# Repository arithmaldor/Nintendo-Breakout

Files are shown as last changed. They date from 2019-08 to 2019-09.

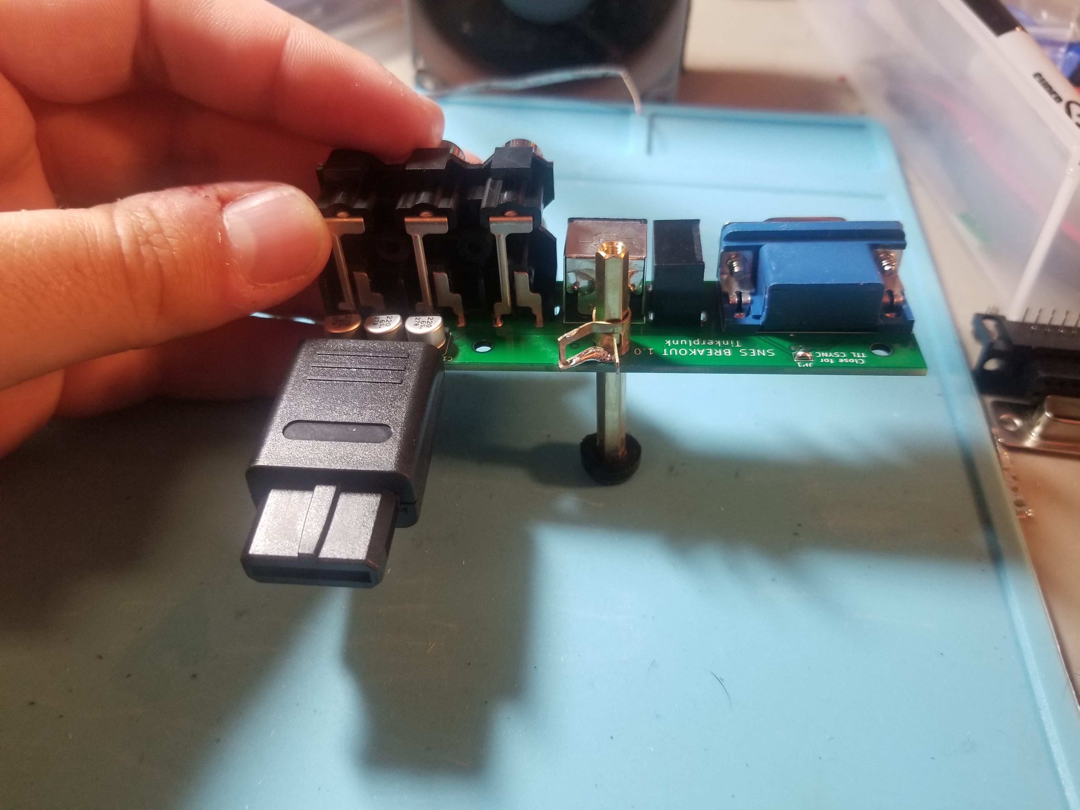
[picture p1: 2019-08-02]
Photos/20190725_023714.jpg

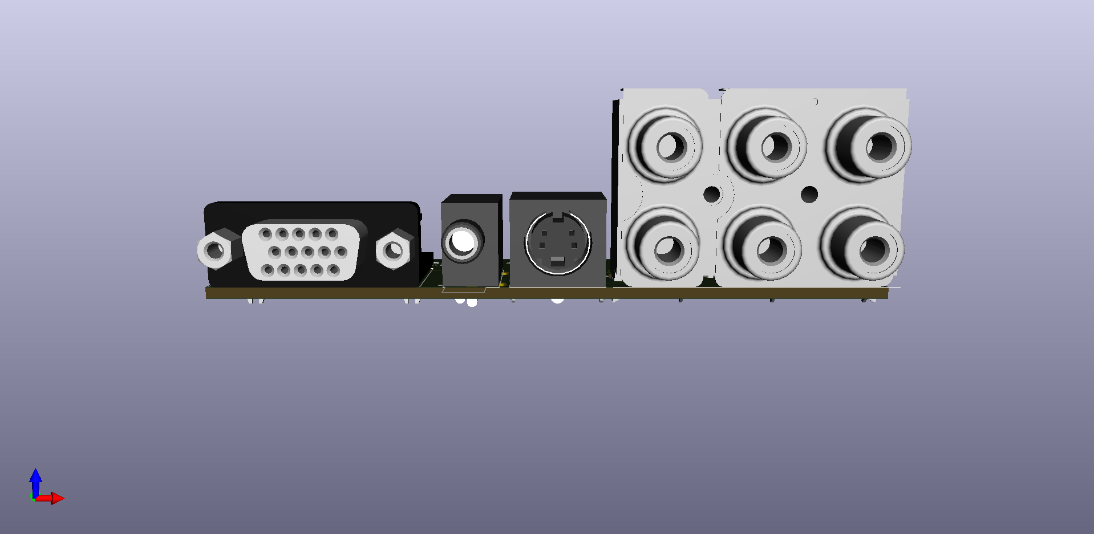
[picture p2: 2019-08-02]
Renders/Front 3D.png

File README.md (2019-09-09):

# Copyright and Disclaimer
Copyright: Jacob Proctor

This documentation describes Open Hardware and is licensed under the
CERN OHL v. 1.2.

You may redistribute and modify this documentation under the terms of the
CERN OHL v.1.2. (http://ohwr.org/cernohl). This documentation is distributed
WITHOUT ANY EXPRESS OR IMPLIED WARRANTY, INCLUDING OF
MERCHANTABILITY, SATISFACTORY QUALITY AND FITNESS FOR A
PARTICULAR PURPOSE. Please see the CERN OHL v.1.2 for applicable
conditions

# Nintendo Multi-out Breakout
Breaks out all of the signals from the Nintendo Muliout so you can easily access them. 

# Operation
Plug in and go. There is a solder jumper to set the csync coming from the HD-15 port as TTL or 75ohm. Closed is TTL, open is 75 ohm. If you only plan to use this in TTL mode the resistor is not required.
This adapter can only break out signals that are already present. Unmodded SNES Jr. will only output composite, unmodded N64's will only ouput CVBS and S-video, same for Gamecube.
A cool extra feature is that this breakout lets you easily output component YPbPr from the GCDual and N64Advanced mods.

# PAL Systems
This was designed with NTSC systems in mind and is not compatible with PAL systems.

# Parts
Refer to BOM.csv for all components. For the support leg, use any appropriately long brass/metal m3 standoff/pillar and screw a rubber foot to the bottom. Solder a 5mm spring clamp to the bottom of the board to adjust the height.
For a Gamecube with Gameboy Player, standoffs may need to be screwed into each other (stacked) to reach the needed height.

# Case
The incredible [Magic Trashman](https://twitter.com/MagicTrashman) was kind enough to design 3D printable cases for both my Nintendo and PSX breakouts. They are under the same license as the PCB and are free to use, but if you order through thingiverse you can leave him a nice tip. Current designs fit the height of the original PS1 and the original SNES, but can be easily adjusted for height if you have some basic 3D design skills. They are held together with 2x 14mm M3 machine screws.
Pictures: https://t.co/ojJ8epfZXH?amp=1
Thingiverse: https://t.co/7dF171BqaF?amp=1
Bonus: If you plug the Nintendo/Sony connector into the console and screw the PCB into the bottom of the case, it makes it a lot easier to solder the connector to the board as it is held in place.

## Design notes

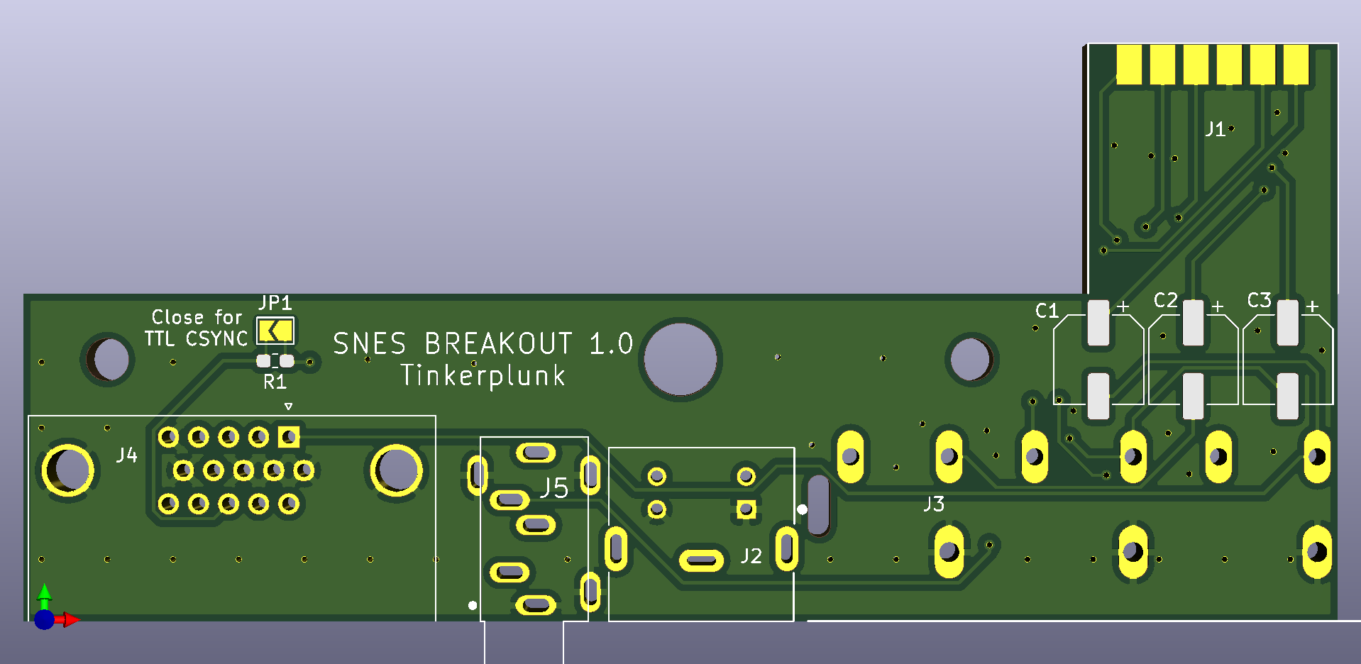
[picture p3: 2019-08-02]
Renders/Top.png

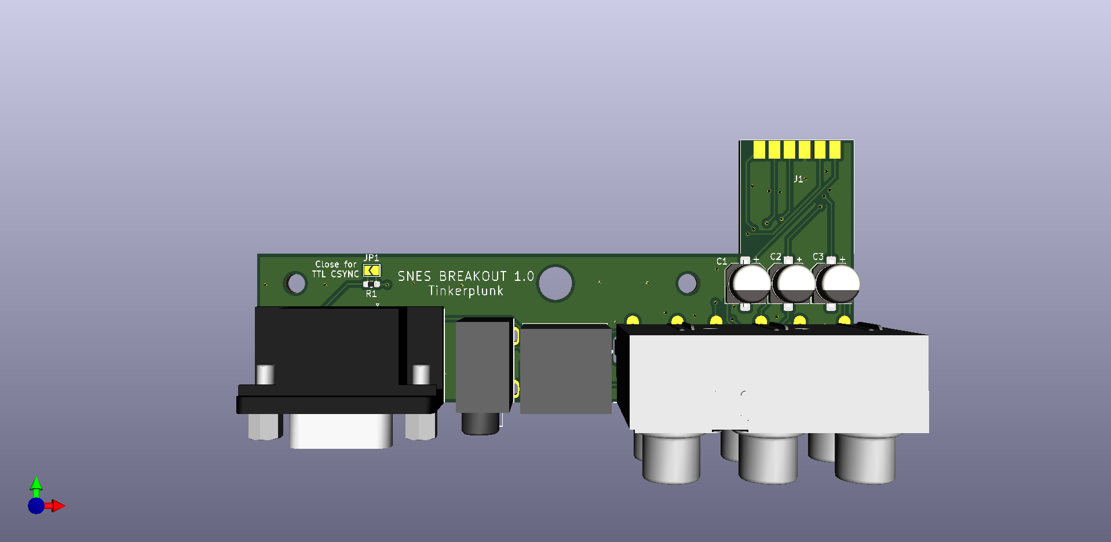
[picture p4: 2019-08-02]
Renders/Top 3d.png

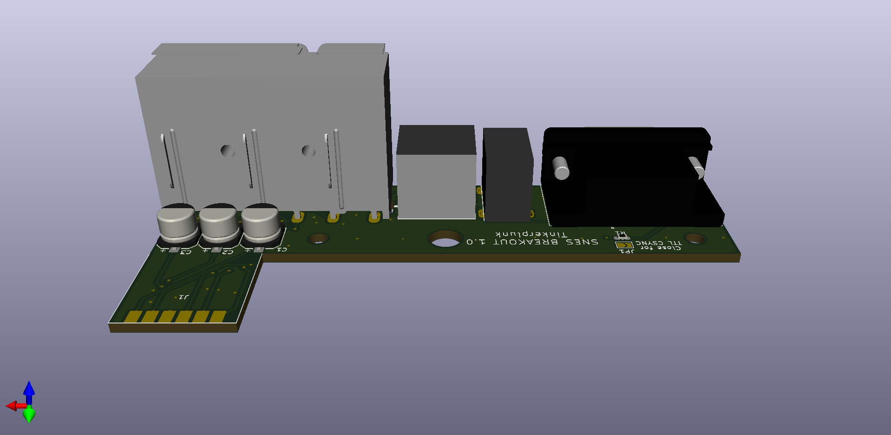
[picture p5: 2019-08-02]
Renders/Back 3D.png

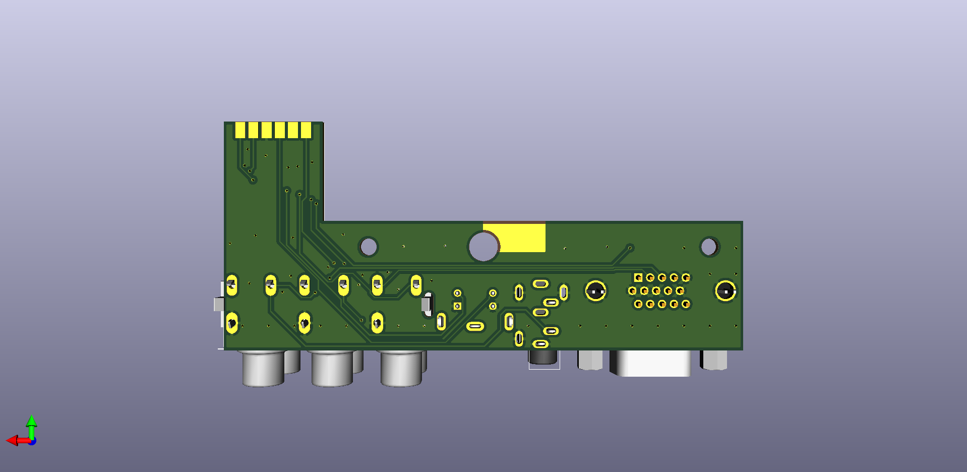
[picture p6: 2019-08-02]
Renders/Bottom.png

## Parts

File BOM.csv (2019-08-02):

Reference | Value | Footprint | MPN | Datasheet | Link | Alt Link | Alt Link 2 | Qty
C1-C3 | 220uF | 6.3x5.4mm | EEE0JA221WP | https://media.digikey.com/pdf/Data%20Sheets/Panasonic%20Electronic%20Components/S_Series,Type_V_Rev2018.pdf | https://www.digikey.com/product-detail/en/panasonic-electronic-components/EEE-0JA221WP/PCE3858CT-ND/766234 | https://lcsc.com/product-detail/Aluminum-Electrolytic-Capacitors-SMD_PANASONIC-EEE0JA221WP_C178494.html |  | 3
J1 | Nintendo Multiout Connector |  |  |  | https://console5.com/store/nintendo-snes-super-famicom-n64-av-multi-out-plug-for-custom-rgb-cables-repair.html |  |  | 1
J2 | S-Video | Mini Din 4 | MD-40 S, SG, SM or SGK | http://service.powerdynamics.com/ec/Catalog17/Section%2011.pdf | https://www.digikey.com/product-detail/en/cui-inc/MD-40SM/CP-2240-ND/96935 | https://www.arrow.com/en/products/md-40sm/cui-inc |  | 1
J3 | Headphone Jack | 3 pin | SJ1-3533NG | https://www.cui.com/product/resource/digikeypdf/sj1-353xng.pdf | https://www.digikey.com/product-detail/en/cui-inc/SJ1-3533NG/CP1-3533NG-ND/738701 | https://www.arrow.com/en/products/sj1-3533ng/cui-inc | https://lcsc.com/product-detail/Audio-Video-Connectors_Boom-Precision-Elec-3-5mmAudio-sockets-PJ325_C26230.html | 1
J4 | DB15 Female High Density | DB15 HD Female | ICD15S13E6GV00LF | https://www.amphenol-icc.com/media/wysiwyg/files/drawing/c-cd-0012.pdf | https://www.digikey.com/product-detail/en/amphenol-icc-fci/ICD15S13E6GV00LF/609-2802-ND/1090326 | https://www.arrow.com/en/products/icd15s13e6gv00lf/amphenol-fci | https://lcsc.com/product-detail/D-Sub-Connectors_VGA-002_C138387.html | 1
J5 | 3x2_RCA | Stacked RCA 2 high 3 long. LR,TB: GBRYWR | RCA-628N1-14 |  | https://ebay.us/PmOF6q |  |  | 1
R1 | 330 Ohm | Metric 0603 | RC0603FR-07330RL | http://www.yageo.com/documents/recent/PYu-RC_Group_51_RoHS_L_10.pdf | https://www.digikey.com/product-detail/en/yageo/RC0603FR-07330RL/311-330HRCT-ND/730109 | https://lcsc.com/product-detail/Chip-Resistor-Surface-Mount_330R-330R-1_C105881.html |  | 1

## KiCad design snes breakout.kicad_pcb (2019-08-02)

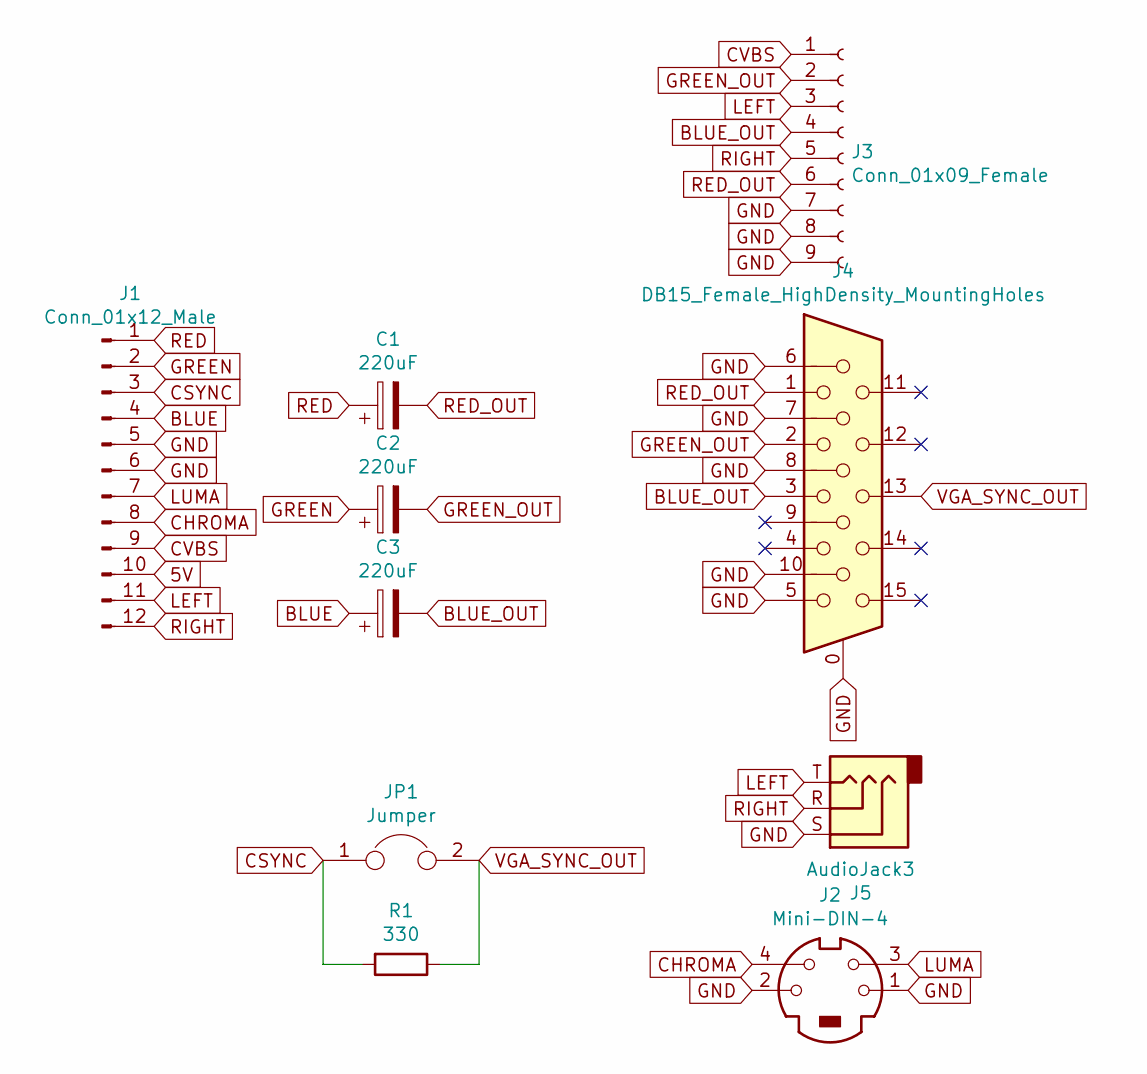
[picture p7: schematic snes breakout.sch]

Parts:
C1, C2, C3: 220uF; CP_Elec_6.3x5.4
J1: Conn_01x12_Male; SNES_PLUG
J2: Mini-DIN-4; CUI_MD-40SG
J3: Conn_01x09_Female; 3x2_RCA
J4: DB15_Female_HighDensity_MountingHoles; VGA
J5: AudioJack3; CUI_SJ1-3533NG
JP1: Jumper; SolderJumper-2_P1.3mm_Open_TrianglePad1.0x1.5mm
R1: 330; R_0603_1608Metric_Pad1.05x0.95mm_HandSolder

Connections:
5V: J1.10
BLUE: C3.1, J1.4
BLUE_OUT: C3.2, J3.4, J4.3
CHROMA: J1.8, J2.4
CSYNC: J1.3, JP1.1, R1.2
CVBS: J1.9, J3.1
GND: J1.5, J1.6, J2.1, J2.2, J3.7, J3.8, J3.9, J4.0, J4.5, J4.6, J4.7, J4.8, J4.10, J5.S
GREEN: C2.1, J1.2
GREEN_OUT: C2.2, J3.2, J4.2
LEFT: J1.11, J3.3, J5.T
LUMA: J1.7, J2.3
RED: C1.1, J1.1
RED_OUT: C1.2, J3.6, J4.1
RIGHT: J1.12, J3.5, J5.R
VGA_SYNC_OUT: J4.13, JP1.2, R1.1

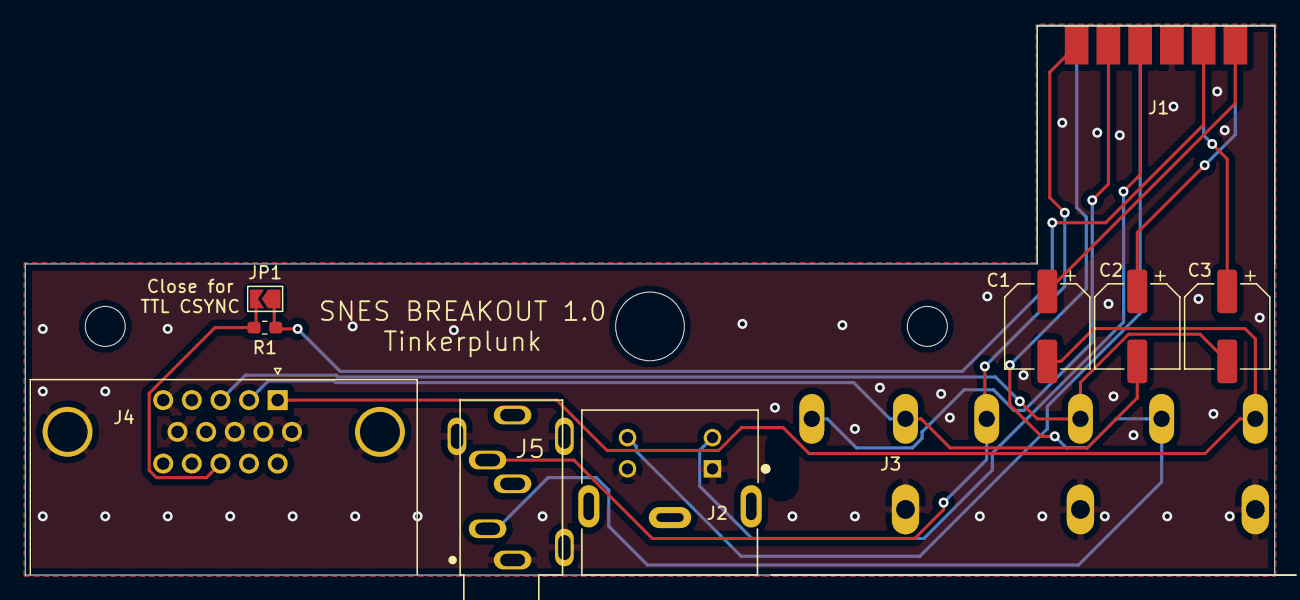
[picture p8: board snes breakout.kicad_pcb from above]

Board: 2 copper layers, 100.0 x 44.0 mm, 10 parts (0 on the bottom side), 14 nets.

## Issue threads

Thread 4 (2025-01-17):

Add warning that R1 is 330 ohms, not 75 ohms for "75 ohm sync"

aus101, 2025-01-17:
Not everyone has studied analog video like you or me or carefully reads a bill of materials. The Tinkerplunk SNES breakout adapter I bought came with a 75 ohm R1. Easy to see "750" and the meter reading. This makes you look bad when the PCB has Tinkerplunk printed on it, particularly if someone damages their expensive scaler. My idea is to add "330 OHMS" on the silk screen and explain the resistance value in the readme.

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

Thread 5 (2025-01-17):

Upgrade 220uF to 330uF

aus101, 2025-01-17:
220uF is the minimum acceptable value. Theory is AC couple to protect against voltage transients from either the console or the television. No exception on any retro console + official cable. Downside is the high pass filter. 220uF on a 75 ohm load forms a 10 Hz cutoff that slides under the critical 25 Hz PAL or 30 Hz NTSC field rate. Maybe 10-20 years of wear and tear later, a 220uF at 20% tolerance degrades to 110uF. Now we have a 20 Hz cutoff that [eats into the black levels](https://www.youtube.com/watch?v=VEDqRtmZNNg).

Since this amazing product isn't capable of being cheapest tier $9.99 USD/CAD in any case, I think it can justify 3x 330uF at about 3x6 cents extra (quantity of 10 pricing) to outlast the console. Higher capacitance also has lower ESR. I thought that was great you used tier 1 brand Panasonic. At 330uF, there's also a rated for 2000 hours option versus 1000 hours. Capacitors don't go bad at that time, but the capacitance can no longer be guaranteed to fall in the 20% range. Meaning more rated hours is a general sign of quality.

I haven't bought from LCSC but here's what I found for DigiKey: https://www.digikey.com/en/products/detail/panasonic-electronic-components/EEE-0JA331XP/766028

Some nice console mods and video converters use 330uF tantalum, which probably the best option, but it doesn't come in the same packaging.

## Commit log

2019-07-02 finished schematic, started board layout
    [snes breakout.kicad_pcb, snes breakout.sch]
2019-07-03 laid outline, placed components
    [snes breakout.kicad_pcb]
2019-07-03 Laid tracks, generated gerbers
    [snes breakout-B_Cu.gbl, snes breakout-B_Mask.gbs, snes breakout-B_SilkS.gbo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]
2019-07-08 Generated gerbers
    [snes breakout-B_Cu.gbl, snes breakout-B_Mask.gbs, snes breakout-B_SilkS.gbo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]
2019-07-31 Fixed footprints
    Need to redo routing
    [snes breakout.kicad_pcb]
2019-08-02 Fixes
    Fixed routing, removed some mask on the bottom to solder the spring on. Ready for action.
    [snes breakout-B_Cu.gbl, snes breakout-B_Mask.gbs, snes breakout-B_SilkS.gbo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]
2019-08-02 Finishing touches
    added renders and photos, BOM, license, etc.
    [BOM.csv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]
2019-09-09 Added case links
